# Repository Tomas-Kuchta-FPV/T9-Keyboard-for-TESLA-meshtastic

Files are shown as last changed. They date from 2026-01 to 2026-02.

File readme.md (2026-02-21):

# T9 Keyboard for TESLA meshtastic
> This is an experimental, low-polish project and without docs.  
It’s shared for reference and tinkering, not as a ready-to-build design.  
Proceed only if you’re comfortable filling in the gaps yourself.  

It's a sub part for an undocumented project that I'm calling TESLA meshtastic.  
Its main purpuse is to find out if a T9 style (4x3) keyboard can be used as a text input for meshtastic.  
The idea is boroved from Travel Buddy. As this idea still lies in my head.  
    
## TESLA meshtastic
Features:
- Speaker with volume control
- T9 style keyboard
- navigation button
- USB-A powered
- Eink?

## Arduino nano code
It should interface the 3x4 keyboard to I2C.

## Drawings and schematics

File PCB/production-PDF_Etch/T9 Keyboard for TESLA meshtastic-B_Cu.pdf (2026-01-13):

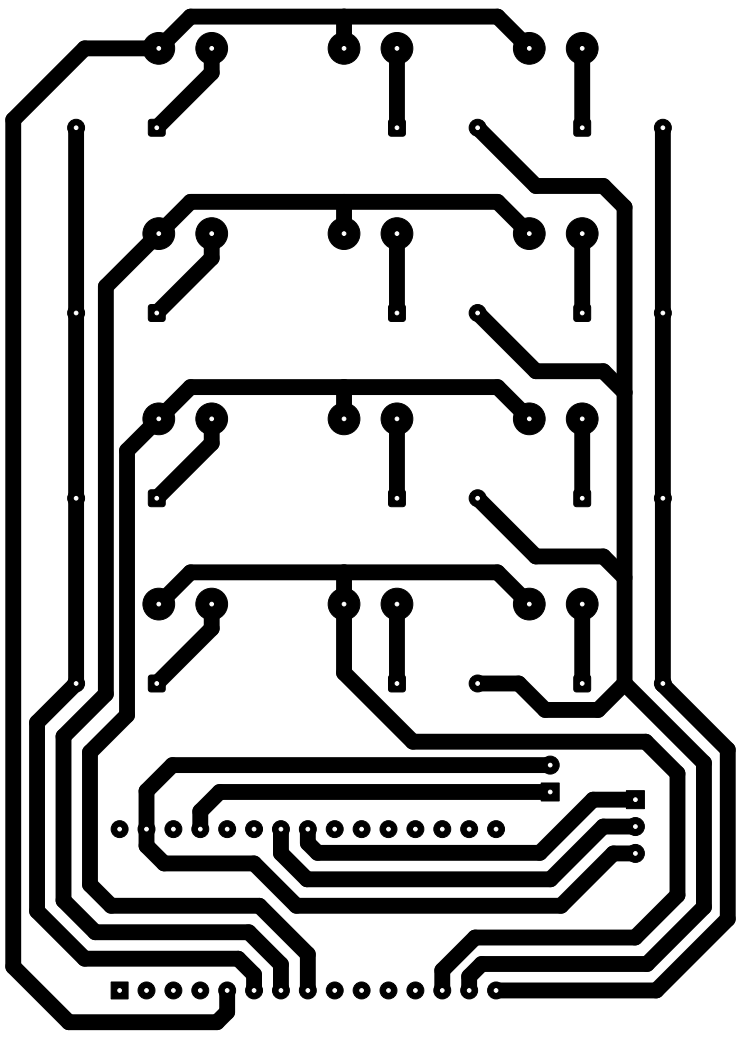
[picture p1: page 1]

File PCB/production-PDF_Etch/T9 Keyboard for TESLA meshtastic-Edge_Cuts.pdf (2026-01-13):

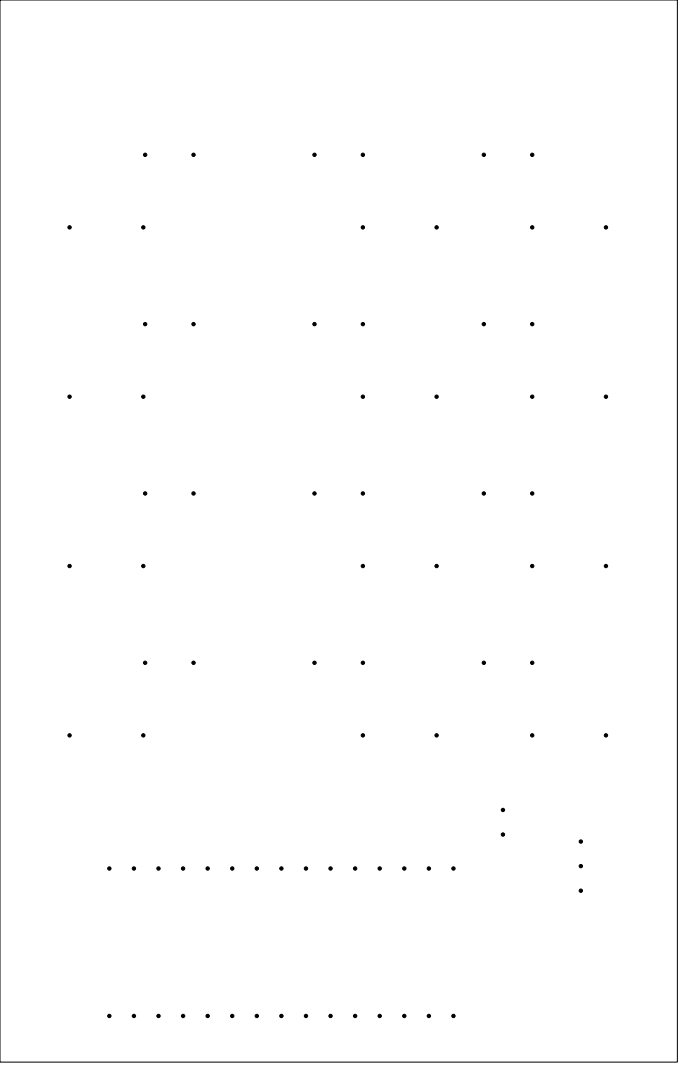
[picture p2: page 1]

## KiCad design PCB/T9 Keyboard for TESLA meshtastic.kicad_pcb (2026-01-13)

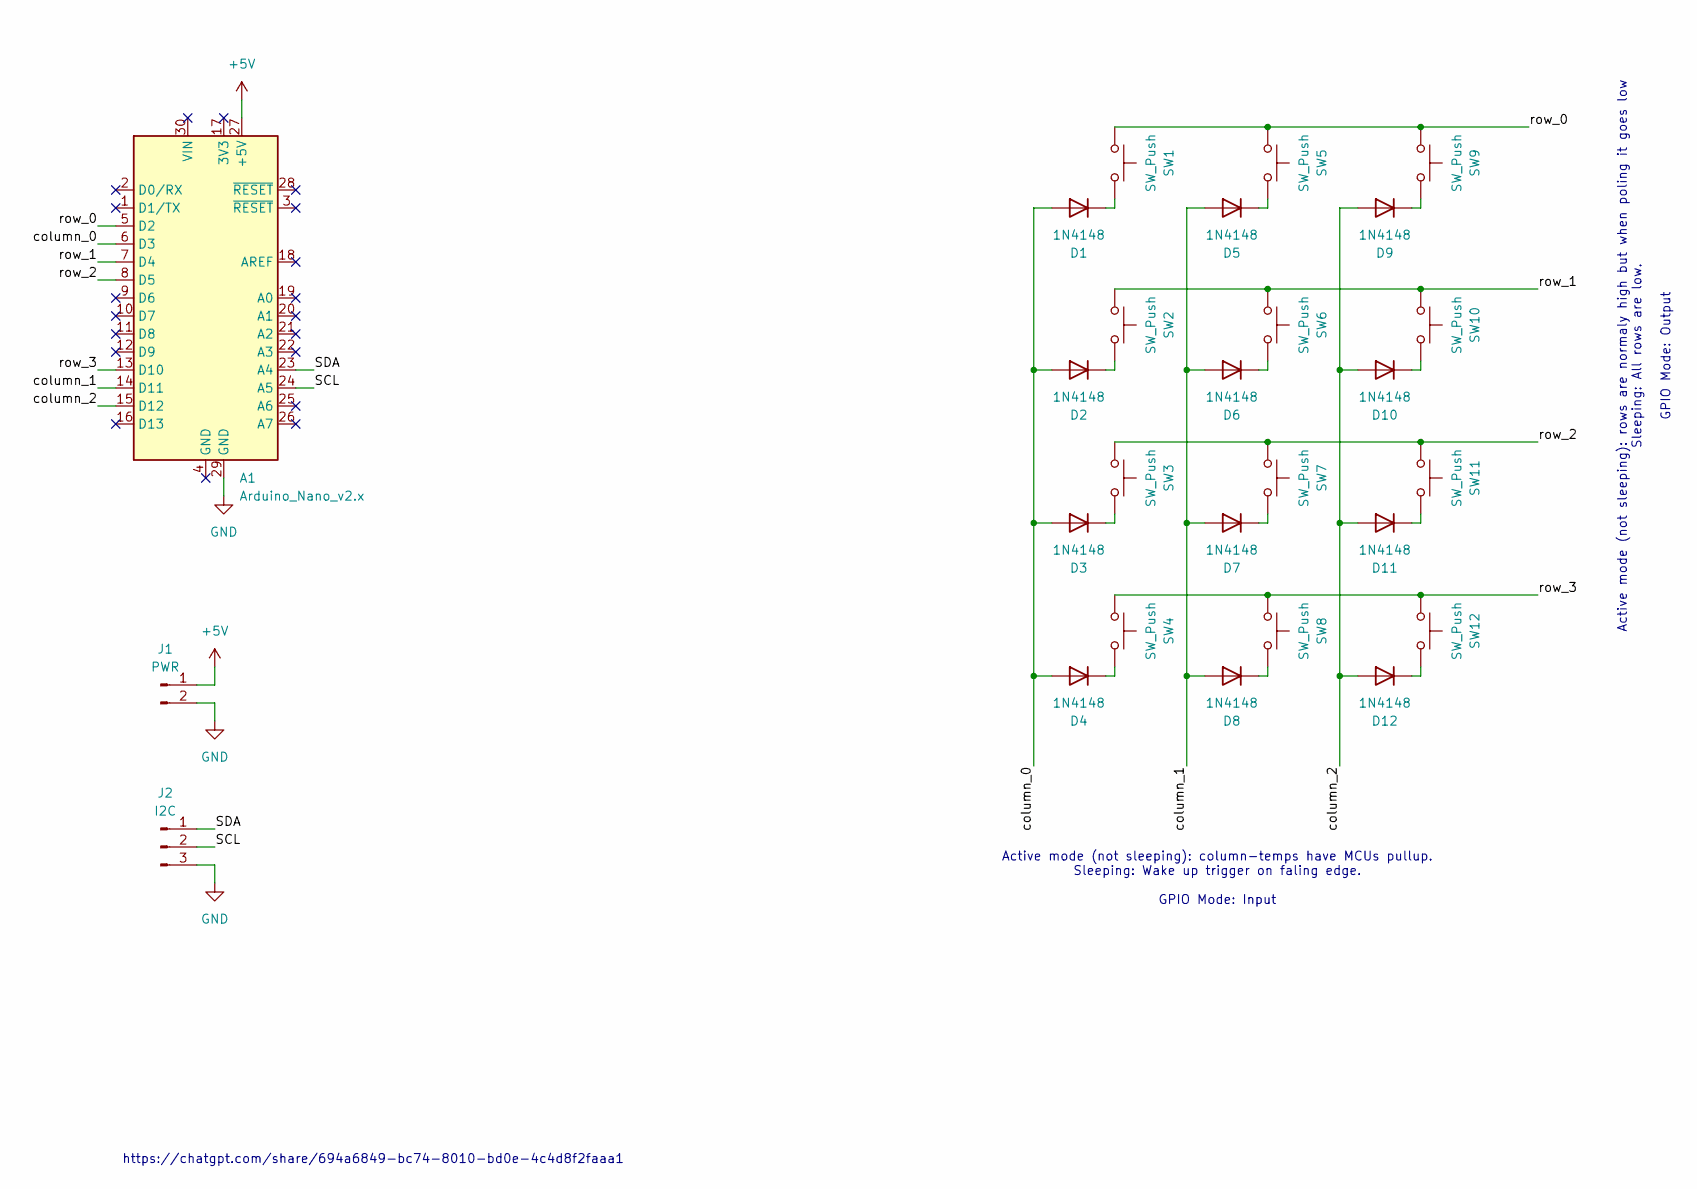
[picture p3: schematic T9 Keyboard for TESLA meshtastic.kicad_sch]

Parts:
A1: Arduino_Nano_v2.x; Arduino_Nano
D1, D2, D3, D4, D5, D6, D7, D8, D9, D10, D11, D12: 1N4148; D_DO-35_SOD27_P7.62mm_Horizontal; LCSC C60580
J1: PWR; PinSocket_1x02_P2.54mm_Vertical
J2: I2C; PinSocket_1x03_P2.54mm_Vertical
SW1, SW2, SW3, SW4, SW5, SW6, SW7, SW8, SW9, SW10, SW11, SW12: SW_Push; TESLA-3 FK 573 00; LCSC C318884

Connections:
+5V: A1.27 (+5V), J1.1
/SCL: A1.24 (A5), J2.2
/SDA: A1.23 (A4), J2.1
/column_0: A1.6 (D3), D1.2 (A), D2.2 (A), D3.2 (A), D4.2 (A)
/column_1: A1.14 (D11), D5.2 (A), D6.2 (A), D7.2 (A), D8.2 (A)
/column_2: A1.15 (D12), D9.2 (A), D10.2 (A), D11.2 (A), D12.2 (A)
/row_0: A1.5 (D2), SW1.1, SW5.1, SW9.1
/row_1: A1.7 (D4), SW2.1, SW6.1, SW10.1
/row_2: A1.8 (D5), SW3.1, SW7.1, SW11.1
/row_3: A1.13 (D10), SW4.1, SW8.1, SW12.1
GND: A1.29 (GND), J1.2, J2.3
unnamed: D1.1 (K), SW1.2
unnamed: D2.1 (K), SW2.2
unnamed: D3.1 (K), SW3.2
unnamed: D4.1 (K), SW4.2
unnamed: D5.1 (K), SW5.2
unnamed: D6.1 (K), SW6.2
unnamed: D7.1 (K), SW7.2
unnamed: D8.1 (K), SW8.2
unnamed: D9.1 (K), SW9.2
unnamed: D10.1 (K), SW10.2
unnamed: D11.1 (K), SW11.2
unnamed: D12.1 (K), SW12.2

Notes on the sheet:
https://chatgpt.com/share/694a6849-bc74-8010-bd0e-4c4d8f2faaa1
Active mode (not sleeping): rows are normaly high but when poling it goes low Sleeping: All rows are low. GPIO Mode: Output
Active mode (not sleeping): column-temps have MCUs pullup. Sleeping: Wake up trigger on faling edge. GPIO Mode: Input

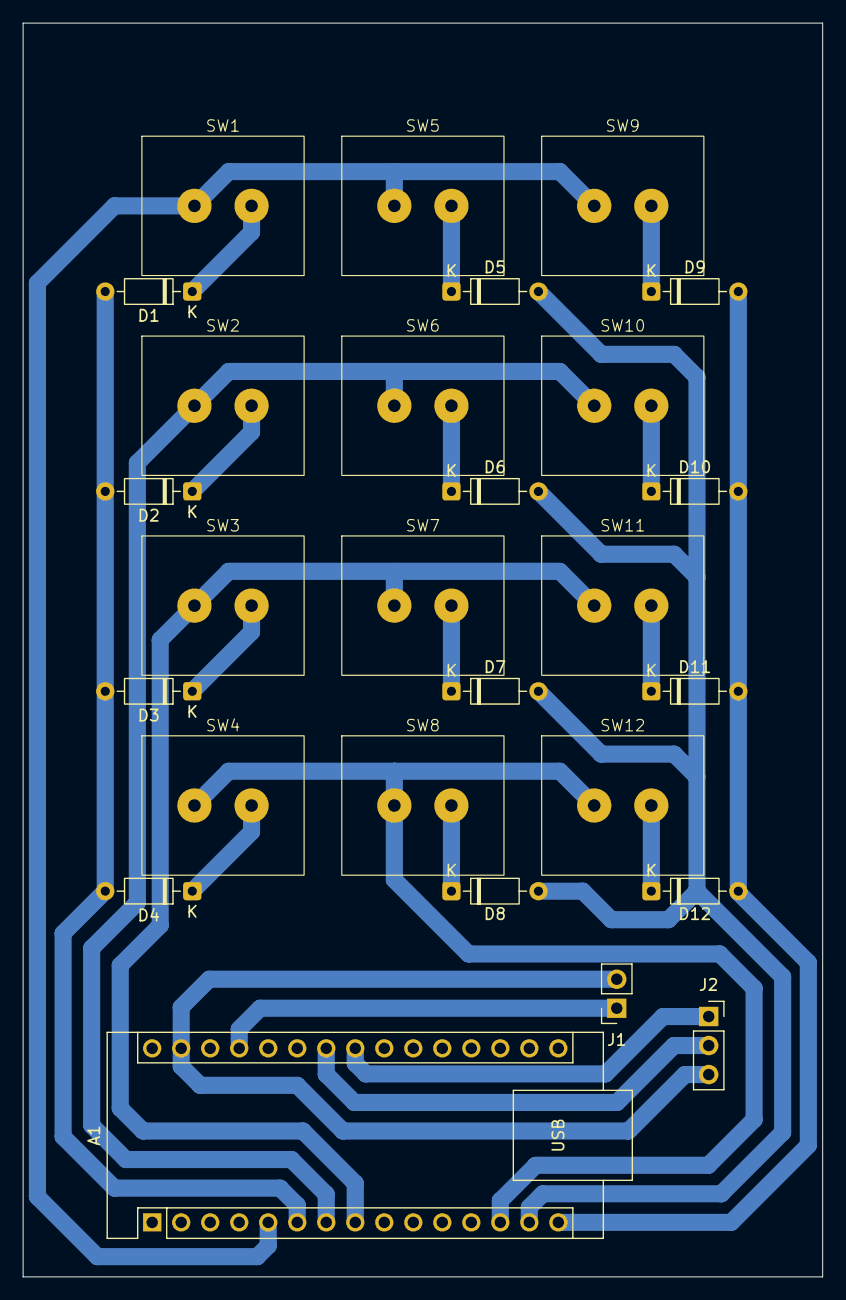
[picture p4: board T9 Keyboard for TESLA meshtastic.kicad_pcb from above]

Board: 2 copper layers, 70.0 x 109.8 mm, 27 parts (0 on the bottom side), 23 nets.

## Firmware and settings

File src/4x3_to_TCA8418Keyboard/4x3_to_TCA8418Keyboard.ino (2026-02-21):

#include <Wire.h>
#include <avr/sleep.h>
#include <avr/interrupt.h>
#include <avr/power.h>

// -------- I2C Configuration --------
#define I2C_SLAVE_ADDRESS 0x34  // TCA8418 keyboard address (Meshtastic uses this)
#define I2C_BUFFER_SIZE 16

// -------- Keypad Configuration --------
const uint8_t ROWS[] = {2, 4, 5, 10};
const uint8_t COLS[] = {3, 11, 12};
const uint8_t ROW_COUNT = 4;
const uint8_t COL_COUNT = 3;
const uint8_t NUM_KEYS = ROW_COUNT * COL_COUNT;

// -------- Interrupt Pins (for wakeup) --------
const uint8_t INT_PIN_1 = 6;   // INT0 or INT1 (check your board)
const uint8_t INT_PIN_2 = 7;   // INT0 or INT1 (check your board)

// -------- State Management --------
volatile bool systemWakeUp = false;
volatile uint8_t i2cBuffer[I2C_BUFFER_SIZE];
volatile uint8_t i2cWriteIndex = 0;
volatile bool newKeyEvent = false;

// Key debounce and timing
#define DEBOUNCE_MS 20
#define SCAN_INTERVAL_MS 10

uint32_t lastScanTime = 0;
uint8_t lastKeyState[NUM_KEYS] = {0};
uint8_t currentKeyState[NUM_KEYS] = {0};

// -------- Interrupt Handlers --------

// INT0 or INT1 external interrupt
ISR(INT1_vect) {
  systemWakeUp = true;
}

ISR(INT0_vect) {
  systemWakeUp = true;
}

// I2C events
volatile uint8_t currentRegister = 0;

void onI2CReceive(int byteCount) {
  if (byteCount > 0) {
    currentRegister = Wire.read();  // First byte is register address
    byteCount--;
    
    // Handle any data written after register address
    while (byteCount > 0 && Wire.available()) {
      uint8_t data = Wire.read();
      if (i2cWriteIndex < I2C_BUFFER_SIZE) {
        i2cBuffer[i2cWriteIndex++] = data;
      }
      byteCount--;
    }
  }
}

void onI2CRequest() {
  // TCA8418 detection: register 0x90 should return 0x00
  if (currentRegister == 0x90) {
    Wire.write(0x00);
  } else if (currentRegister == 0x84) {
    // Keyboard event register - return buffered key events
    Wire.write((const uint8_t*)i2cBuffer, i2cWriteIndex);
    i2cWriteIndex = 0;
  } else {
    // Default register response for other register addresses
    Wire.write(0x00);
  }
}

// -------- Setup --------

void setup() {
  // Configure pins
  configureKeypadPins();
  configureInterruptPins();
  
  // Initialize I2C slave
  Wire.begin(I2C_SLAVE_ADDRESS);
  Wire.onReceive(onI2CReceive);
  Wire.onRequest(onI2CRequest);
  
  // Enable external interrupts for wakeup
  EIMSK |= (1 << INT0) | (1 << INT1);  // Enable both INT0 and INT1
  EICRA |= (1 << ISC00) | (1 << ISC10); // Trigger on any change
}

// -------- Main Loop --------

void loop() {
  // Check if system should wake up
  if (!systemWakeUp) {
    enterSleep();
  }
  
  systemWakeUp = false;
  
  // Scan keypad while awake
  uint32_t now = millis();
  if (now - lastScanTime >= SCAN_INTERVAL_MS) {
    scanKeypad();
    lastScanTime = now;
  }
  
  // Brief debounce/activity window, then return to sleep
  if (millis() - lastScanTime > DEBOUNCE_MS) {
    // Ready for next sleep
  }
}

// -------- Keypad Functions --------

void configureKeypadPins() {
  // Rows as outputs (inactive HIGH)
  for (uint8_t i = 0; i < ROW_COUNT; i++) {
    pinMode(ROWS[i], OUTPUT);
    digitalWrite(ROWS[i], HIGH);
  }
  
  // Columns as inputs with pullups
  for (uint8_t i = 0; i < COL_COUNT; i++) {
    pinMode(COLS[i], INPUT_PULLUP);
  }
}

void configureInterruptPins() {
  // Set interrupt pins as inputs with pullups
  pinMode(INT_PIN_1, INPUT_PULLUP);
  pinMode(INT_PIN_2, INPUT_PULLUP);
}

void scanKeypad() {
  for (uint8_t row = 0; row < ROW_COUNT; row++) {
    // Set all rows HIGH
    for (uint8_t i = 0; i < ROW_COUNT; i++) {
      digitalWrite(ROWS[i], HIGH);
    }
    
    // Drive current row LOW
    digitalWrite(ROWS[row], LOW);
    delayMicroseconds(10);  // Settle time
    
    // Read columns
    for (uint8_t col = 0; col < COL_COUNT; col++) {
      uint8_t keyIndex = row * COL_COUNT + col;
      uint8_t isPressed = (digitalRead(COLS[col]) == LOW) ? 1 : 0;
      
      currentKeyState[keyIndex] = isPressed;
      
      // Detect state change
      if (currentKeyState[keyIndex] != lastKeyState[keyIndex]) {
        lastKeyState[keyIndex] = currentKeyState[keyIndex];
        queueKeyEvent(keyIndex, isPressed);
      }
    }
  }
  
  // Return all rows to HIGH (idle)
  for (uint8_t i = 0; i < ROW_COUNT; i++) {
    digitalWrite(ROWS[i], HIGH);
  }
}

void queueKeyEvent(uint8_t keyIndex, uint8_t pressed) {
  // Queue key event for I2C transmission
  // Format: [keyIndex] [pressed]
  if (i2cWriteIndex + 2 <= I2C_BUFFER_SIZE) {
    i2cBuffer[i2cWriteIndex++] = keyIndex;
    i2cBuffer[i2cWriteIndex++] = pressed ? 0x80 : 0x00;  // High bit indicates press vs release
    newKeyEvent = true;
  }
}

// -------- Sleep Functions --------

void enterSleep() {
  // Power down unused peripherals
  power_timer0_disable();
  power_timer1_disable();
  power_timer2_disable();
  power_spi_disable();
  power_usart0_disable();
  power_adc_disable();
  
  // Prepare keypad for sleep (rows LOW to detect key press)
  for (uint8_t i = 0; i < ROW_COUNT; i++) {
    digitalWrite(ROWS[i], LOW);
  }
  
  // Enter power-down sleep mode
  set_sleep_mode(SLEEP_MODE_PWR_DOWN);
  sleep_enable();
  sei();  // Ensure interrupts are enabled
  sleep_cpu();
  
  // ---- System wakes here ----
  sleep_disable();
  
  // Re-enable peripherals (only if needed)
  power_timer0_enable();
  power_usart0_enable();
  
  // Restore keypad to active state
  for (uint8_t i = 0; i < ROW_COUNT; i++) {
    digitalWrite(ROWS[i], HIGH);
  }
}

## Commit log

2025-12-22 Drew up schematic.
    [T9 Keyboard for TESLA meshtastic.kicad_pcb, T9 Keyboard for TESLA meshtastic.kicad_sch]
2025-12-24 Finished the PCB.
    [T9 Keyboard for TESLA meshtastic.kicad_pcb, T9 Keyboard for TESLA meshtastic.kicad_sch]
2026-01-13 Finished the PCB
    [T9 Keyboard for TESLA meshtastic.kicad_pcb]
